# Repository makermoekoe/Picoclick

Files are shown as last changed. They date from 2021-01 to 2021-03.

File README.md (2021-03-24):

# Picoclick



(Click on the image for a small video.)

People who follow my Instagram already knew what I have worked on several months now with tons of PCB iterations... But now it's done!
The Picoclick is a simple IOT-Button in a very small package. The dimensions of the PCB are only 18x20mm and the height with a 300909 battery is only about 10mm. It is able to connect to your local WiFi at an amazingly high speed of about 1.5 seconds in average. Yes, as it calls IOT-Button, it uses WiFi of course! That enables tons of possibilities for that little device. The original idea behind it was to control my local lights, outlets and radiators in my smart home through a single button press - or two, or a button hold, ... As the Picoclick **doesn't use deepsleep** it enables many possible button combinations, because the button isn't connected to the reset line of the MCU, like it is mainly done on such devices (even on my own old dashbuttons...). Nevertheless, the Picoclick can be used somewhere else of course! I have successfully integrated it into MQTT and IFTTT, but it can be used to control everything which has at least a WiFi connection. Additionally it has four external GPIOs which can be used to control things and read sensors for other projects. BTW. the Picoclick can be flashed with that sexy USB-C jack, because it has an onboard CP2102N USB-Serial bridge.

Here are some specs of the Picoclick:
- “Pico” size: 18.0×20.0mm board outline
- Single button interface
- Three WS2812 LEDs for visual feedback
- ESP8285 MCU board (behaves like the ESP8266, just a little less memory)
- Four external GPIOs (as solder pads)
- Fully integrated LiPo charging solution with a great protection circuit (including Over(dis)charge, reverse polarity, short circuit protection and more)
- Charging and programming via the USB Type-C jack (integrated CP2102N USB-Serial bridge)
- A 30mAh (9x9x3mm pouch cell) battery is enough to reaches over 350 clicks.
- Ultra low stand-by current

The Picoclick is still available to buy [here](https://hhtronik.com/product/picoclick-v2-2-by-maker-moekoe/).

</a>

</a>

</a>

For battery info, check my [website](https://makermoekoe.com/2020/12/08/picoclick/).

## GPIOs

Function | GPIO | Mode
-------- | -------- | --------
WS2812 Din | GPIO14   | Output
Button | GPIO12   | Input
Latch* | GPIO13   | Output
Charge Stat. | GPIO4  | Input
Ext IO1  |  GPIO6   | IO
Ext IO2  |  GPIO7   | IO
Ext IO3  |  GPIO8   | IO
Ext IO4  |  GPIO10  | IO

*The Picoclick doesn't use the deepsleep functionality of the MCU, because it uses too much power. It comes with its own power latching circuit. The MCU can control its own power with the latch pin. Once it is held high the ESP8285 will get power and as soon as it is pulled low the ESP8285 will shut down. Easy peasy...

## Circuit

The circuit is based on the following components:
- MCU ESP8285 with external 24MHz oscillator and external Rainsun AN2051 chip antenna
- CP2102N USB-Serial bridge with autoreset circuit based on the MUN5214DW1T1G dual transistor
- RT9193 3,3v voltage regulator
- LiPo charger BRCL4054BME (MCP73831 alternative, pin compatible)
- XB5353A LiPo protection with SEU7401U reverse polarity protection; power measurement via voltage divider
- power latching circuit based on 4148 SOD523 diodes
- WS2812 2020 mini RGB LEDs

## Code

You can just run every code that you have in your mind, just make sure that the Picoclick needs to be powered in one of the following two ways:
- button press
- latching pin

So please keep in mind that it will shut down if you release the button and doesn't pull the latch pin high. Typically you have to call following two lines of code at first.
```
pinMode(latch,OUTPUT);
digitalWrite(latch,HIGH);
```
To turn the Picoclick off, you have to call:
```
digitalWrite(latch,LOW);
```

The charge status GPIO can be used to read the state of the onboard LiPo charger. Use the following code first to enable this feature:
```
pinMode(status_charger,INPUT_PULLUP);
int status = digitalRead(status_charger);
```
Where ```status_charger```is the GPIO4. The ```status```variable will hold the status. It returns 0 when the battery is charging through the USB port. It returns 1 if the battery is fully charged.

### Fast WiFi connection
To enable a really fast WiFi connection you have to put your local access point into a fixed WiFi channel. In doing so, the Picoclick is able to know that channel which saves around a second while connecting to the AP. Another thing is the BSSID, which can be found on your access points settings. Just enter your local IP into your favorite internet browser and find that terrifying number somewhere. Add that settings to the following lines of code:

```
const uint8_t bssid[6] = {0x80, 0x71, 0x7A, 0x3F, 0x8B, 0x63}; //put your access points bssid here
const int wifi_channel = 9; //set the channel in your access points settings
```

I have attached three simple examples in the code folder of this repo. A bare_minimum sketch with just a simple led animation, an mqtt example and an IFTTT example.

Update 13.12.2020: I have added the buttonpress_counter.cpp for interrupt counting the button presses. This can be used for several application. Next is to add the button hold functionality, but that shouldn't be a problem.

## Uploading code with PlatformIO

Before starting: The Picoclick has to be connected to an external power supply via those pads on the bottom of the PCB. They are labeled as + and -. The voltage should be between 3.5 volts and 6 volts. Without power supply, the Picoclick won't be recognized by your computer.

As my favorite IDE is PlatformIO I will show you an easy way on how to setup your Picoclick there. Nevertheless all this is possible in the Arduino IDE as well.

PlatformIO has the great advantage that it has plenty of boards available in the base version. So you don't have to install the ESP8266 board separately, like it is done in the Arduino IDE.
Actually, PlatformIO is just a plugin for VisualStudio Code which can be downloaded here: https://platformio.org/install/ide?install=vscode
Inside the VSCode you can install the plugin afterwards. The link has a great and detailed description on how to proceed.

Once you have everything installed correctly, you should see the PIO Home screen after restarting VSCode. Now you can open an existing project or just create a new one. When creating a new one then select the following options:
- Name: Picoclick (just a name)
- Board: Generic ESP8285 Module (Espressif) (you can just search for esp8285, because searching it manually would take an hour...)
- Framework: Arduino (default)

Afterwards you got a new project in your workspace which contains two important files. The ```main.cpp``` and the ```platform.ini```. The ```main.cpp``` file contains the code (which you can found in this repo) and the ```platform.ini``` file contains informations about the board, usb upload port, monitor speed and everything which you could possibly set. The minimum platform.ini file should look like this for all the Picoclick sketches:
```
[env:esp8285]
platform = espressif8266
board = esp8285
framework = arduino

upload_speed = 460800
upload_port = /dev/cu.usbserial-1410
monitor_speed = 115200
upload_resetmethod = nodemcu
```
The only thing you have to change is the `upload_port`. You can spot the right one in your PIO Home screen in the Devices tab. Once you're done you can perform several actions in the bottom left corner of VSCode: compile, upload, serial monitor, ...

While uploading a sketch to the Picoclick you have to press and hold the button of it during the complete uploading process. It should automatically reboot and start your code. The button can be released afterwards.

## External GPIO's
The Picoclick has four external GPIO's (GPIO6, GPIO7, GPIO8, GPIO10) which are labeled as IO's. These can be both inputs or outputs. The other pads on the top side of the Picoclick (button side) are power supply pads, which can be used like this:

Label | Description
-------- | --------
VU | USB voltage (5 volt)
V1 | 3.3 volt
V2 | 3.3 volt
G1 | GND
G2 | GND

An overview of the external pads is given below.

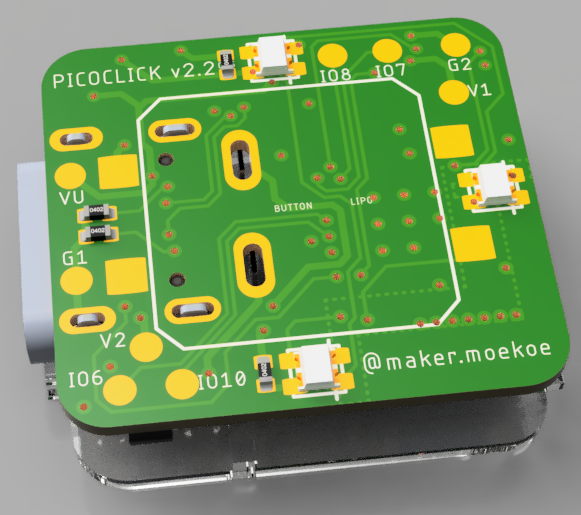
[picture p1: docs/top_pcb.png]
</a>

## Set charging current
The Picoclick is build to be used with small Lipo batteries with a capacity of around 20mAh-30mAh. Therefore we set the charging current for this battery to 21mA through the `R_prog` resistor of the charger chip. The value of `R_prog`is 47,5kOhm. With the equation `I_charge = 1000V / R_prog` the charging current can be set individually (R_prog in kOhm). The resistor to set this current is marked in the image below.

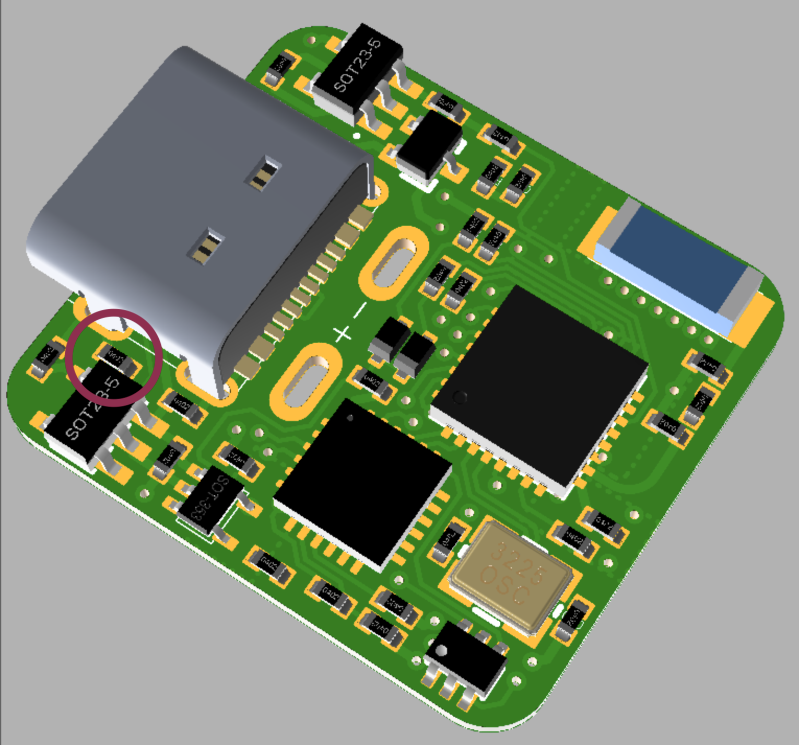
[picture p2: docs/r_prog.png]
</a>

Have fun! :)

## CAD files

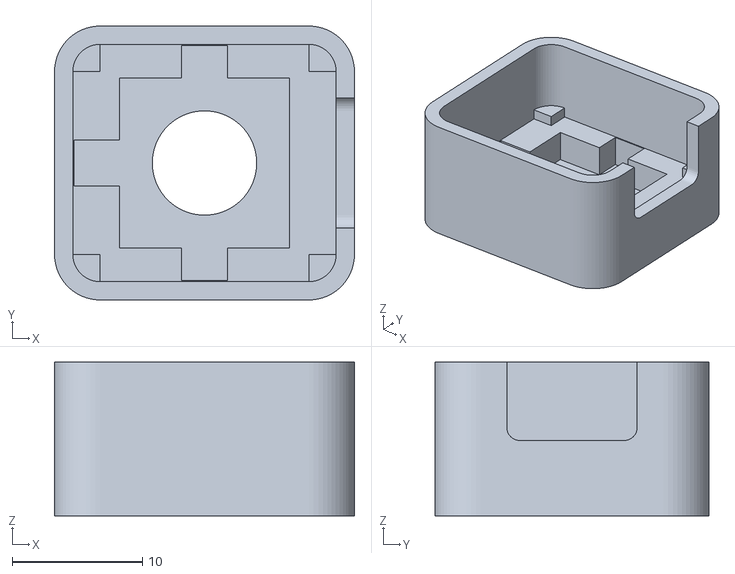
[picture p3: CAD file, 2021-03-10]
3dfiles/picoclick_fdm_case_bot.stl
23.0 x 21.0 x 11.8

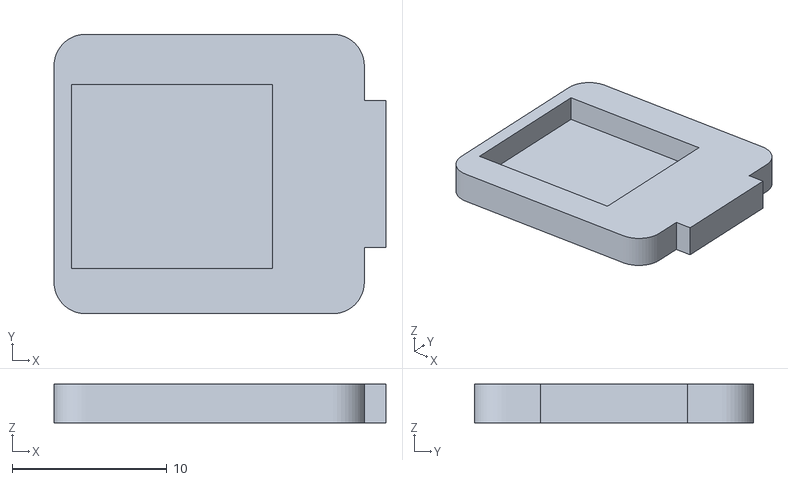
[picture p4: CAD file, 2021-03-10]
3dfiles/picoclick_fdm_case_top.stl
21.5 x 18.1 x 2.50

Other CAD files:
3dfiles/picoclick_v2_2.f3d

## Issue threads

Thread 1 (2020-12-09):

Double Click, Click & Hold

nccchirag, 2020-12-09:
Can you also provide a sample with the below functionality included?

1. Click
2. Double Click
3. Long Press -- Click & Hold

For double click/click&hold, with the latching logic will I have to power on picoclick with a single click first and then double click to operate?
Can you elaborate on this please?

makermoekoe, 2020-12-09:
I will add examples for all this later.
To answer your second question: No, the first (power on click) can be read out as normal. So for a double press you only have to press the button twice.

makermoekoe, 2021-03-11:
Hey, I just came across this issue thread and I wanna mention that there is a fully testet button counter sketch with and without MQTT in the repo. It can count button presses and button holds. (It is the last button press which can be hold)

The sketch answers with a green blinking animation if it just counts single presses and with a red animation if the last button press was held. All this is based on interrupts, so it is possible during the WLAN connect period.

Closed 2020-12-09.

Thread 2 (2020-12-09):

WiFi force sleep when picoclick is charging/connected to the USB

nccchirag, 2020-12-09:
All your samples turn off WiFi when USB charging cable is connected and picoclick is charging. Shouldn't it be continuously ON with latch pin HIGH? as, it is connected to a power source.

**Use Case:**
I have a picoclick with battery & it has drained, so, I connect it to my PC/Powerbank/Power Brick on the desk and now since it is connected to power, I would still want the button functions to be used rather than first unplugging it and then operating it.

Does the charging hardware limit this?

Please guide

makermoekoe, 2020-12-09:
Hey, the attached files are just some basic examples.
The idea behind this was, that I want a simple animation while the battery is charging. Nevertheless, it is possible that you can enable button press detection while the USB cable is plugged in. Therefore you have to add the `digitalRead(button)` part inside the loop. If you don't want any animation, you can delete the entire if-cause around the `status_mcp` variable and it will behave like it isn't plugged to USB.

If it will help, I can upload a new code for this.

Closed 2020-12-09.

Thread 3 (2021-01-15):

Dead on Arrival?

suhlig, 2021-01-15:
Hi,

my two brand new PicoClicks just arrived. They look neat, but there is no new device found
when I connect it using USB-C. Other ESPs I have appear as `/dev/cu.usbserial-1410`, but both PicoClicks I bought seem dead.

Is there something to be aware of? Any advice on how to move forward?

Regards

Steffen

makermoekoe, 2021-01-15:
Hey Steffen,
the on board USB driver is powered by battery, so probably you have to connect a power supply between 3.5v and 6v to the battery pads behind the USB-C jack. Your PC should recognize the Picoclicks afterwards.

Closed 2021-01-15.

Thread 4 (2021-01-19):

Silkscreen not readable

derpicknicker1, 2021-01-19:
As i wrote in a mail to @makermoekoe  I'm not able to read the silkscreen on the PCB. So it is not possible to determine which of the extension pads has which functionality.
Many thanks to @makermoekoe, who reacted instantly by adding informations about the pads to the documentaion.
Anyways, i want to post some pictures of my board, to show that it is a real issue and not me beeing blind :smile:

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

makermoekoe, 2021-01-22:
Overview added to the repo.

Closed 2021-01-22.

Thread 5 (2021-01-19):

Wrong factor in getBatteryVoltage()

derpicknicker1, 2021-01-19:
In the example code for mqtt and ifttt there is a method to read the battery voltage in millivolts. But the factor in this method is wrong. It will return about 7900mV for a fully charged battery.

https://github.com/makermoekoe/Picoclick/blob/062b08edbb41c2c131e96a83faa8be95ed6d7e97/code/mqtt.cpp#L60

For the voltage divider used on the board the values are `R1 = 1MΩ` and `R2 = 250kΩ`. So the equation in the comment above should result in a factor of 5.

For me, this gives a reading of ~4200mV when the battery is fully charged, which should be correct.

SergioEscuder, 2021-01-22:
Mine also. How did you find the voltage divider resistor values?

derpicknicker1, 2021-01-22:
I asked @makermoekoe

makermoekoe, 2021-01-22:
Yes, the voltage divider is `1M:250k` and therefore should be 5. 4200mV for a fully charged Lipo battery sounds great.
I have updated the values in the code.
Thanks for sharing.

Closed 2021-01-22.

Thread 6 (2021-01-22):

Extremely low charging current

SergioEscuder, 2021-01-22:
Plugging a USB power consumption monitor reports a charging current of 0.02A (20mA).
Is this normal? What should be the correct value?
A battery will take forever to charge at this rate.
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

derpicknicker1, 2021-01-22:
Yes, it is normal. The charging current is set by a resistor connected to the cahrge controller. The resistors value is 47,5kOhm. With the equation `I = 1000V / R` the charge current is calculated. This results in `I = 1000V / 47500Ohm = 21mA`

See also [Datasheet](https://datasheet.lcsc.com/szlcsc/BLUE-ROCKET-BRCL4054BME_C328563.pdf) page 10.

makermoekoe, 2021-01-22:
A charging current of around 21mA is totally fine. We set the Rprog of the LiPo charger to 47,5kOhm which results (depending on the equation in the datasheet `I=1000V/R` in 21mA.
The Picoclick is build to be used with totally small Lipo batteries of around 20-30mAh. A charging current of 20mA is something around 1C charging rate which is totally fine.

makermoekoe, 2021-01-22:
I have added a description to the repo with the highlighted `R_prog`. Depending on the equation above you can set the charging current depending on your battery. Keep in mind that even these small batteries can be dangerous.

Closed 2021-01-22.

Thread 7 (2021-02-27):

schematics and fusion 360 export

frankbolton, 2021-02-27:
Hi-

I saw your posts on instagram and wanted to learn from your design.
I want to make a pico size (similar battery) wearable device that works with BLE and a sensor.
Do you plan to share your electronic design (specifically the schematic) as I want to use WS2811 LEDs with a lipo battery

Derbyshire10, 2021-12-01:
@makermoekoe I would also like to alter the design to better suit different projects. Could you please publish the schematic?

enekochan, 2022-02-09:
Yes please, even a simplified schema would be nice to learn how you achieved to include the usb charger, the ESP chip and the WiFi antena. I would love to understand how it all works. Thank you!

Derbyshire10, 2022-03-03:
@makermoekoe The new project Picoclick-C3 has the documents needed to recreate the board with your own changes.

https://github.com/makermoekoe/Picoclick-C3

enekochan, 2022-03-03:
Thank you! Didn't knew about that repo.

Closed 2022-07-18.

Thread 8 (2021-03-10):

BSSID to uint8_t {Solved}

timothyvisual, 2021-03-10:
Hi,

I really like the Picoclick and i'm fairly new to coding. Sorry if this is a noob question.

 The thing i struggle with is transfroming the BSSID  **e2:63:da:ae:30:67** to:
`const uint8_t bssid[6] = {0x80, 0x71, 0x7A, 0x3F, 0x8B, 0x63}; //put your access points bssid here`

Do you use a site for this convertion?

Thank you for you're time.

makermoekoe, 2021-03-10:
Hey, it is probably as easy as adding the `0x` before every digit. In your case this would result in
`const uint8_t bssid[6] = {0xE2, 0x63, 0xDA, 0xAE, 0x30, 0x67}; `

I you have any other questions then feel free to ask 🙂

Closed 2021-03-10.

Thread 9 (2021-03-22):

Battery Size

neofuturism, 2021-03-22:
What would happen if I plug a 500MAH battery to the Picoclick?
will it explode :)

makermoekoe, 2021-03-22:
Haha 😁 Of course you can do it! The only difference is that it needs longer to charge. You can change the charging current via a resistor like it is shown in the repo :)

neofuturism, 2021-03-22:
Awesome, thank you,
I finally found a cool project for the Pico!!

makermoekoe, 2021-03-24:
Where do you gonna use i? :)

Closed 2021-04-16.

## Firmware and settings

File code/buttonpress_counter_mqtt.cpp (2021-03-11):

/**
 * read button as interrupt for the Picoclick v2.2
 *
 * This sketch counts button presses and flashes the LEDs as often as the button was pressed.
 * For interrupt use of ESP8266, ESP8285 and ESP32 you have to call: #define ISR_PREFIX ICACHE_RAM_ATTR
 * https://github.com/platformio/platform-espressif8266/issues/160
 *
 * The Picoclick can power itself by holding the latch pin high.
 * Pulling the latch to ground will switch it off.
 *
 * Use WiFi.mode(WIFI_OFF) & WiFi.forceSleepBegin() in the setup for power saving when you don't wanna use WiFi.
 *
 * 02.03.2021 by @maker.moekoe (Moritz König)
 *
 */

#include <Arduino.h>
#include <ESP8266WiFi.h>
#include <FastLED.h>
#include <PubSubClient.h>

#define ISR_PREFIX ICACHE_RAM_ATTR

const char* ssid = "XXX";
const char* password = "XXX";
const char* mqtt_server = "192.168.2.103";
const uint8_t bssid[6] = {0x80, 0x71, 0x7A, 0x3F, 0x8B, 0x63}; // anpassen
const int wifi_channel = 9;

const char* mqtt_topic = "/home/pico5/#";
const char* mqtt_topic_state = "/home/pico5/state";
const char* mqtt_client = "pico5";

WiFiClient espClient;
PubSubClient client(espClient);

#define LIPO_MINIMAL 3200 //mV
#define CONNECTION_TIMEOUT 6000 //ms

#define NUM_LEDS 3
CRGB leds[NUM_LEDS];

const int button = 12;
const int latch = 13;
const int status_mcp = 4;

volatile int interruptCounter = 1;
volatile unsigned long t_press = millis();
volatile bool btn_state = true;
bool longpress = false;

volatile boolean first_press = true;
volatile unsigned long last_interrupt_time = 0;

ISR_PREFIX void handleInterrupt() {
  if (millis() - last_interrupt_time > 70 || first_press){
    interruptCounter++;
    first_press = false;
    btn_state = digitalRead(button);
  }
  last_interrupt_time = millis();
  t_press = millis();
}

int getBatteryVoltage() {
  float factor = 5.0; // (R1+R2)/R2, +/- X
  return (float(analogRead(0)) / 1023.0 * factor) * 1000.0; //returns mV
}

void ConnectionCheck(){
  int v = getBatteryVoltage();
  if (v < LIPO_MINIMAL || millis() > CONNECTION_TIMEOUT) {
    for (int b = 100; b > 10; b--) {
      for (int i = 0; i < NUM_LEDS; i++) leds[i] = CRGB(b, 0, 0);
      FastLED.show();
      delay(10);
    }
    delay(200);
    digitalWrite(latch, LOW);
  }
}

void setup() {
  pinMode(latch, OUTPUT);
  digitalWrite(latch, HIGH);

  pinMode(button, INPUT);
  attachInterrupt(digitalPinToInterrupt(button), handleInterrupt, CHANGE);
  pinMode(status_mcp, INPUT_PULLUP);

  FastLED.addLeds<WS2812, 14, GRB>(leds, NUM_LEDS);
  FastLED.setBrightness(200);
  delay(1);

  WiFi.persistent(false);
  WiFi.mode(WIFI_STA);
  WiFi.begin(ssid, password, wifi_channel, bssid, true);
  delay(1);
  for (int i = 0; i < NUM_LEDS; i++) leds[i] = CRGB(0, 0, 150);
  FastLED.show();

  while (WiFi.status() != WL_CONNECTED) {
    delay(10);
    ConnectionCheck();
  }

  client.setServer(mqtt_server, 1883);

  while (!client.connected()) {
    if (client.connect(mqtt_client)) {
      client.subscribe(mqtt_topic_state);
    }
    ConnectionCheck();
  }
}

void loop() {
  if(digitalRead(button) && interruptCounter >= 0 && btn_state && millis() > t_press + 300){
    for (int i = 0; i < NUM_LEDS; i++) leds[i] = CRGB(150, 0, 0);
    FastLED.show();
    interruptCounter = -interruptCounter;
  }

  if(millis() > t_press + 500) {
    int n_button_press = (interruptCounter > 0) ? interruptCounter / 2 : (interruptCounter - 1) / 2;
    char b[10];
    itoa(n_button_press, b, 10);
    client.publish(mqtt_topic_state, b);

    delay(10);
    WiFi.mode(WIFI_OFF);
    WiFi.forceSleepBegin();

    if(n_button_press < 0) longpress = true;

    for(int n=0; n<abs(n_button_press*2)-1; n++){
      for (int i = 0; i < NUM_LEDS; i++) leds[i] = CRGB(longpress*150*(!(n%2)), (!longpress)*150*(!(n%2)), 0);
      FastLED.show();
      while(digitalRead(button)) delay(1);
      delay(200);
    }

    for (int b = 150; b > 10; b--) {
      for (int i = 0; i < NUM_LEDS; i++) leds[i] = CRGB(longpress*b, !longpress*b, 0);
      FastLED.show();
      delay(2);
    }

    digitalWrite(latch,0);
    delay(200);
  }
}

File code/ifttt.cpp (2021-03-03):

/**
 * mqtt example for the Picoclick v2.2
 * 
 * This sketch activates an IFTTT.
 * 
 * The Picoclick can power itself by holding the latch pin high.
 * Pulling the latch to ground will switch it off.
 * 
 * Use WiFi.mode(WIFI_OFF) & WiFi.forceSleepBegin() in the setup for power saving when you don't wanna use WiFi.
 * 
 * 29.11.2020 by @maker.moekoe (Moritz König)
 * 
 */

#include <Arduino.h>
#include <ESP8266WiFi.h>
#include <FastLED.h>

const char* ssid = "XXX";
const char* password = "XXX";
const uint8_t bssid[6] = {0x80, 0x71, 0x7A, 0x3F, 0x8B, 0x63}; //put your access points bssid here
const int wifi_channel = 9; //set the channel in your access points settings

// IFTTT setup
//const char *host = "maker.ifttt.com";
const char *host = "100.24.23.248";
const char *privateKey = "XXXX";

#define LIPO_MINIMAL 3200

#define NUM_LEDS 3
CRGB leds[NUM_LEDS];

const int button = 12;
const int latch = 13;
const int status_mcp = 4;

bool state = false;

boolean battery_empty = false;
boolean battery_charging = false;
boolean stay_on = false;

int hue = 0;
double pi = 3.141;
double chg_bright = 100;



void send_event(const char *event) {

  WiFiClient client;
  const int httpPort = 80;
  if (!client.connect(host, httpPort)) {
    return;
  }

  // We now create a URI for the request
  String url = "https://maker.ifttt.com/trigger/";
  url += event;
  url += "/with/key/";
  url += privateKey;

  // This will send the request to the server
  client.print(String("GET ") + url + " HTTP/1.1\r\n" +
               "Host: " + host + "\r\n" +
               "Connection: close\r\n\r\n");

  // Read all the lines of the reply from server and print them to Serial,
  // the connection will close when the server has sent all the data.
  while (client.connected())
  {
    if (client.available())
    {
      String line = client.readStringUntil('\r');
    } else {
      // No data yet, wait a bit
      delay(50);
    };
  }

  client.stop();
  // Finished sending the message
}

int getBatteryVoltage() {
  float factor = 5; // (R1+R2)/R2, +/- X
  return (float(analogRead(0)) / 1023.0 * factor) * 1000.0; //returns mV
}

void ChargingStatus() {
  if (digitalRead(status_mcp) == 0) {
    for (int i = 0; i < NUM_LEDS; i++) leds[i] = CHSV((hue + i * 85) % 255, 250, 100);
    FastLED.show();
    delay(50);
    hue = (hue + 1) % 255;
  }
  else {
    //digitalWrite(vdiv_gnd, HIGH);
    CRGB c = CRGB(100, 100, 100);
    if (getBatteryVoltage() > 4100) c = CRGB(0, 100, 0);
    else c = CRGB(100, 50, 0);

    for (int i = 0; i < NUM_LEDS; i++) leds[i] = c;
    FastLED.show();

    delay(3000);
    digitalWrite(latch, LOW);
    delay(1000);
  }
}

void ConnectionCheck(){
  int v = getBatteryVoltage();
    if (v < LIPO_MINIMAL) {
      for (int b = 100; b > 10; b--) {
        for (int i = 0; i < NUM_LEDS; i++) leds[i] = CRGB(b, 0, 0);
        FastLED.show();
        delay(10);
      }

      delay(200);
      digitalWrite(latch, LOW);
    }

    if (millis() > 6000) {
      for (int x = 0; x < 10; x++) {
        for (int i = 0; i < NUM_LEDS; i++){
          leds[i] = CRGB(100, 0, 0);
        } 
        FastLED.show();
        delay(50);
        
        delay(50);
      }
      for (int i = 0; i < NUM_LEDS; i++) leds[i] = CRGB(100, 0, 0);
      FastLED.show();
      delay(200);

      digitalWrite(latch, LOW);
    }
}

void setup() {
  pinMode(latch, OUTPUT);
  digitalWrite(latch, HIGH);

  pinMode(status_mcp, INPUT_PULLUP);

  pinMode(button, INPUT);
  state = digitalRead(button);

  FastLED.addLeds<WS2812, 14, GRB>(leds, 3).setCorrection(TypicalLEDStrip);
  FastLED.setBrightness(200);

  for (int i = 0; i < NUM_LEDS; i++) leds[i] = CRGB(0, 0, 0);
  FastLED.show();

  if (digitalRead(status_mcp) == 0) {
    //usb cable plugged in
    battery_charging = true;

    WiFi.mode(WIFI_OFF);
    WiFi.forceSleepBegin();
    delay(100);
  }
  else {
    //connect & act
    WiFi.persistent(false);
    WiFi.mode(WIFI_STA);
    WiFi.begin(ssid, password, wifi_channel, bssid, true);
    for (int i = 0; i < NUM_LEDS; i++) leds[i] = CRGB(0, 0, 150);
    FastLED.show();

    int c_led = 0;
    while ((WiFi.status() != WL_CONNECTED)) {
      for (int i = 0; i < NUM_LEDS; i++) leds[i] = CRGB(0, 0, sin(3.141*float(c_led+i)/180.0)*150);
      FastLED.show();
      delay(10);

      ConnectionCheck();
      c_led++;
    }

    for (int i = 0; i < NUM_LEDS; i++) leds[i] = CRGB(0, 100, 0);
    FastLED.show();

    send_event("picoclick_1");

    for (int b = 100; b > 10; b--) {
      for (int i = 0; i < NUM_LEDS; i++) leds[i] = CRGB(0, b, 0);
      FastLED.show();
      delay(10);
    }

    digitalWrite(latch, LOW);
    delay(200);
    //never reaching this
  }
}

void loop() {
   if (!stay_on) {
    ChargingStatus();
  }
  else {
    if (digitalRead(button) == 1) {
      delay(100);
      long t = millis();
      while (digitalRead(button) == 1) {

        if (millis() > t + 1000) {

          for (int b = 100; b > 10; b--) {
            for (int i = 0; i < NUM_LEDS; i++) leds[i] = CRGB(b, 0, 0);
            FastLED.show();
            delay(10);
          }

          while (digitalRead(button) == 1) delay(20);

          delay(200);
          digitalWrite(latch, LOW);
          delay(100);
        }
      }
      delay(10);
    }
  }
}

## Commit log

2020-12-08 added 3d fusion360 file
    [picoclick_v2_2.f3d]
2020-12-13 added interrupt button press counter sketch
2020-12-13 added button press description
2021-01-18 updated top pcb overview
2021-01-22 updated the voltage divider value
2021-03-03 added hold functionality
    The Picoclick reads the button presses. If the last button press is a press-and-hold the LEDs will light up red instead of green.
2021-03-10 added fdm printable case
    [picoclick_fdm_case_bot.stl, picoclick_fdm_case_top.stl]
2021-03-11 added MQTT example with button press/hold counter
